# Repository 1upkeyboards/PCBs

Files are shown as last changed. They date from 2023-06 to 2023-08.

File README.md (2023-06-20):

# PCBs
Repository containing production files and schematics for 1upkeyboards pcbs

Shield: [][cc-by-nc-sa]

This work is licensed under a
[Creative Commons Attribution-NonCommercial-ShareAlike 4.0 International License][cc-by-nc-sa].

[][cc-by-nc-sa]

[cc-by-nc-sa]: http://creativecommons.org/licenses/by-nc-sa/4.0/
[cc-by-nc-sa-image]: https://licensebuttons.net/l/by-nc-sa/4.0/88x31.png
[cc-by-nc-sa-shield]: https://img.shields.io/badge/License-CC%20BY--NC--SA%204.0-lightgrey.svg

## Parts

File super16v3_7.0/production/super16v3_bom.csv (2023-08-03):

Designator | Footprint | Quantity | Value | LCSC Part #
C1, C10, C11, C14, C15, C2, C3, C6, C8, C9 | cap_0402_production | 10 | 100n | C77014
C12, C13, C7 | cap_0402_production | 3 | 1u | C77009
C4, C5 | cap_0402_production | 2 | 10u | C77000
D1, D10, D13, D14, D17, D18, D19, D2, D21, D22, D24, D25, D27, D28, D3, D30, D31, D32, D33, D36, D37, D4, D40, D41, D44, D45, D46, D47, D48, D5, D6, D9 | WS2812b_1010 | 32 | ws2812b_1010 | C5349953
D11, D12, D15, D16, D20, D23, D26, D29, D7, D8 | SK6812MINI-E RL_production | 10 | SK6812MINI-E | C524051
D34, D35, D38, D39, D42, D43 | SK6812MINI-E LR_production | 6 | SK6812MINI-E | C524051
F1 | fuse_0805_production | 1 | Polyfuse_Small | C2833485
K1, K10, K11, K12, K13, K14, K15, K16, K2, K3, K4, K5, K6, K7, K8, K9 | MXOnly-1U-Hotswap_no_silk_screen | 16 | KEYSW | C5156480 | Kailh: CPG151101S11
R1, R2 | resistor_0402_production | 2 | 27 | C227342
R3 | resistor_0402_production | 1 | 1k | C375497
R4, R5 | resistor_0402_production | 2 | 5.1k | C138073
SW1 | reset_switch_TL3342_production | 1 | SW_Push | C2886894
U1 | voltage_regulator_production | 1 | XC6206PxxxMR | C347376
U2 | emi_production | 1 | ECMF02-4CMX8 | C717678
U3 | rp2040_flash_production | 1 | W25Q128JVS | C2843335
U4 | rp2040_production | 1 | RP2040 | C2040
USB1 | usb_c_production | 1 | HRO-TYPE-C-31-M-12 | C165948
Y1 | resonator_3_pin_production | 1 | Resonator | C341520

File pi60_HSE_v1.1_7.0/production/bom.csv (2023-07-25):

Designator | Footprint | Quantity | Value | LCSC Part #
C1, C12, C2, C3, C4, C5, C6, C7, C8, C9 | 402 | 10 | 100n | C77014
C10, C11, C15 | 402 | 3 | 1u | C77009
C13, C14 | 805 | 2 | 10u | C77075
D1, D10, D11, D12, D13, D14, D15, D16, D17, D18, D19, D2, D20, D21, D22, D23, D24, D25, D26, D27, D28, D29, D3, D30, D31, D32, D33, D34, D35, D36, D37, D38, D39, D4, D40, D41, D42, D43, D44, D45, D46, D47, D48, D49, D5, D50, D51, D52, D53, D54, D55, D56, D57, D58, D59, D6, D60, D61, D62, D63, D7, D8, D9 | D_SOD-123 | 63 | D | C83528
D64, D65, D66, D67, D68, D69, D70, D71, D72, D73, D74, D75, D76, D77, D78, D79 | LED_WS2812B_PLCC4_5.0x5.0mm_P3.2mm | 16 | WS2812B | C2761795
F1 | 1206 | 1 | Polyfuse_Small | C70076
J3 | 1X04_1MM_RA | 1 | QWIIC_CONNECTORJS-1MM | C160404
K1 - K73 | MXOnly-1U-Hotswap | 73 |  | C5156480 | Kailh: CPG151101S11
R1, R2 | 402 | 2 | 27 | C227342
R3 | 402 | 1 | 1k | C375497
R4, R5 | 402 | 2 | 2.2k | C326602
R6, R7 | 402 | 2 | 5.1k | C138073
SW1 | SW_SPST_TL3342 | 1 | SW_Push | C2886894
U1 | RP2040-QFN-56 | 1 | RP2040 | C2040
U2 | PSON50P300X200X60-9N | 1 | W25Q128JVS | C2843335
U3 | ECMF02-4CMX8 | 1 | ECMF02-4CMX8 | C717678
U4 | SOT-23 | 1 | XC6206PxxxMR | C347376
USB1 | HRO-TYPE-C-31-M-12-Assembly | 1 | HRO-TYPE-C-31-M-12 | C165948
Y1 | 3 Pin Resonator | 1 | Resonator | C341520

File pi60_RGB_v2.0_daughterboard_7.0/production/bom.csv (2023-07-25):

Designator | Footprint | Quantity | Value | LCSC Part #
C1, C12, C2, C3, C4, C5, C6, C7, C8, C9 | cap_0402_production | 10 | 100n | C77014
C10, C11, C15 | cap_0402_production | 3 | 1u | C77009
C13, C14 | cap_0402_production | 2 | 10u | C77000
D1, D10, D11, D12, D13, D14, D15, D16, D17, D18, D19, D2, D20, D21, D22, D23, D24, D25, D26, D27, D28, D29, D3, D30, D31, D32, D33, D34, D35, D36, D37, D38, D39, D4, D40, D41, D42, D43, D44, D45, D46, D47, D48, D49, D5, D50, D51, D52, D53, D54, D55, D56, D57, D58, D59, D6, D60, D61, D7, D8, D9 | diode_SOD-123_production | 61 | D | C83528
D100, D101, D102, D64, D65, D66, D67, D68, D69, D70, D71, D72, D73, D74, D75, D90, D91, D92, D93, D94, D95, D96, D97, D98, D99 | SK6812MINI-E RL_production | 25 | SK6812MINI-E | C524051
D103, D104, D105, D106, D107, D108, D109, D110, D111, D112, D113, D114, D116, D118, D120, D121, D122, D148, D149, D151, D153, D155, D62, D63, D76, D77, D78, D79, D80, D81, D82, D83, D84, D85, D86, D87, D88, D89 | SK6812MINI-E LR_production | 38 | SK6812MINI-E | C524051
D115, D117, D119, D123, D125, D126, D127, D128, D129, D130, D131, D132, D133, D134, D135, D136, D137, D138, D139, D140, D141, D142, D143, D144, D145, D146, D147, D150, D152, D154, D156, D157, D158, D159, D160, D161, D162, D163, D164, D165 | WS2812b_1010 | 40 | 1010 | C5349953
J2 | qwiic_stemmaqt_conn_production | 1 | Unified_Daughterboard | C160404
K1-K61 | MXOnly-1U-Hotswap_no_silk_screen | 61 |  | C5156480 | Kailh: CPG151101S11
R1, R2 | resistor_0402_production | 2 | 27 | C227342
R4 | resistor_0402_production | 1 | 1k | C375497
SW1 | reset_switch_TL3342_production | 1 | SW_Push | C2886894
U2 | rp2040_production | 1 | RP2040 | C2040
U3 | rp2040_flash_production | 1 | W25Q128JVS | C2843335
U5 | voltage_regulator_production | 1 | XC6206PxxxMR | C347376
Y1 | resonator_3_pin_production | 1 | Resonator | C341520

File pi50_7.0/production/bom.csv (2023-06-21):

Designator | Footprint | Quantity | Value | LCSC Part #
D1, D10, D11, D12, D13, D14, D15, D16, D17, D18, D19, D2, D20, D21, D22, D23, D24, D25, D26, D27, D28, D29, D3, D30, D31, D32, D33, D34, D35, D36, D37, D38, D39, D4, D40, D41, D42, D43, D44, D45, D46, D47, D48, D49, D5, D50, D51, D52, D53, D54, D55, D56, D57, D58, D59, D6, D60, D7, D8, D9 | Diode No Label | 60 | D
D100, D101, D102, D103, D104, D105, D106, D107, D108, D73, D74, D75, D76, D77, D78, D79, D80, D81, D82, D83, D84, D97, D98, D99 | MX_SK6812MINI-E LR no keepout no via | 24 | SK6812MINI-E
D109, D110, D111, D112, D113, D114, D115, D116, D117, D118, D119, D120, D121, D61, D62, D63, D64, D65, D66, D67, D68, D69, D70, D71, D72, D85, D86, D87, D88, D89, D90, D91, D92, D93, D94, D95, D96 | MX_SK6812MINI-E RL no keepout no via | 37 | SK6812MINI-E
H1, H2, H3, H4 | MountingHole_3.2mm_M3 | 4 | MountingHole
H10, H5, H6, H7, H8, H9 | MountingHole_5.3mm_M5 | 6 | MountingHole
J1 | PinHeader_1x15_P2.54mm_Vertical | 1 | Conn_01x15_Female
J2 | PinHeader_1x04_P2.54mm_Vertical | 1 | I2C Display
K1, K10, K11, K12, K13, K14, K15, K16, K17, K18, K19, K2, K20, K21, K22, K23, K24, K25, K26, K27, K28, K29, K3, K30, K31, K32, K33, K34, K35, K36, K37, K38, K39, K4, K40, K41, K42, K43, K44, K45, K46, K47, K48, K49, K5, K50, K51, K52, K53, K54, K55, K56, K57, K58, K59, K6, K60, K7, K8, K9 | MXOnly-1U-NoLED_tight | 60 | KEYSW
K61 | MXOnly-2U-ReversedStabilizers-NoLED_tight | 1 | KEYSW
SW1 | RotaryEncoder_EC11 | 1 | Rotary_Encoder_Switch
U1 | MODULE_SC0915 | 1 | SC0915

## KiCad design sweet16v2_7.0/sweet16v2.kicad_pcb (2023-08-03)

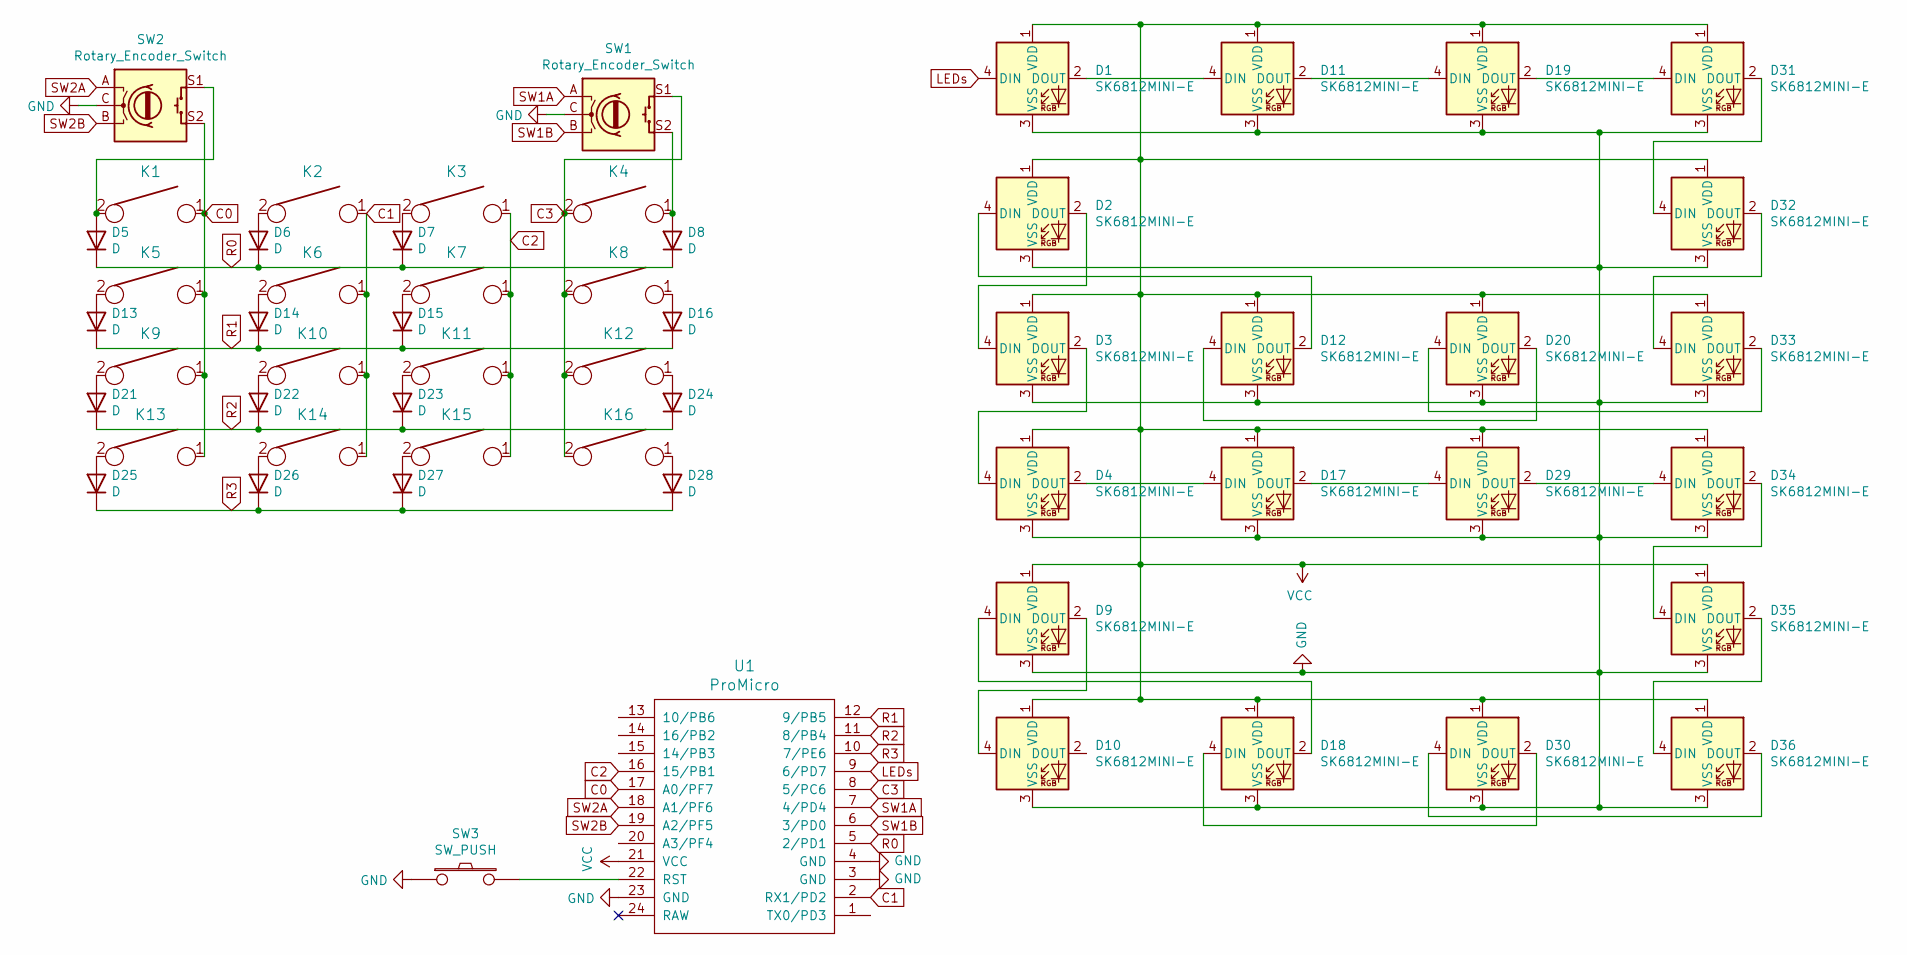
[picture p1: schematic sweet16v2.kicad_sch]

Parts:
D1, D3, D4, D10, D11, D12, D17, D18, D19, D20, D29, D30, D31, D33, D34, D36: SK6812MINI-E; MX_SK6812MINI-E_upward_facing
D2, D9, D32, D35: SK6812MINI-E; MX_SK6812MINI-E_flipped
D5, D6, D7, D8, D13, D14, D15, D16, D21, D22, D23, D24, D25, D26, D27, D28: D; D_SOD123_axial
K1, K2, K3, K4, K5, K6, K7, K8, K9, K10, K11, K12, K13, K14, K15, K16: KEYSW; MXOnly-1U-NoLED
SW1, SW2: Rotary_Encoder_Switch; RotaryEncoder_EC11
SW3: SW_PUSH; SW_SPST_TL3342
U1: ProMicro; ArduinoProMicro

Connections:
C0: K1.1, K5.1, K9.1, K13.1, SW2.S2, U1.17 (A0/PF7)
C1: K2.1, K6.1, K10.1, K14.1, U1.2 (RX1/PD2)
C2: K3.1, K7.1, K11.1, K15.1, U1.16 (15/PB1)
C3: K4.2, K8.2, K12.2, K16.2, SW1.S1, U1.8 (5/PC6)
GND: D1.3 (VSS), D2.3 (VSS), D3.3 (VSS), D4.3 (VSS), D9.3 (VSS), D10.3 (VSS), D11.3 (VSS), D12.3 (VSS), D17.3 (VSS), D18.3 (VSS), D19.3 (VSS), D20.3 (VSS), D29.3 (VSS), D30.3 (VSS), D31.3 (VSS), D32.3 (VSS), D33.3 (VSS), D34.3 (VSS), D35.3 (VSS), D36.3 (VSS), SW1.C, SW2.C, SW3.1, U1.3 (GND), U1.4 (GND), U1.23 (GND)
LEDs: D1.4 (DIN), U1.9 (6/PD7)
unnamed: D1.2 (DOUT), D11.4 (DIN)
unnamed: D2.2 (DOUT), D3.4 (DIN)
unnamed: D3.2 (DOUT), D4.4 (DIN)
unnamed: D5.2 (A), K1.2, SW2.S1
unnamed: D6.2 (A), K2.2
unnamed: D7.2 (A), K3.2
unnamed: D8.2 (A), K4.1, SW1.S2
unnamed: D9.2 (DOUT), D10.4 (DIN)
unnamed: D11.2 (DOUT), D19.4 (DIN)
unnamed: D2.4 (DIN), D12.2 (DOUT)
unnamed: D12.4 (DIN), D20.2 (DOUT)
unnamed: D13.2 (A), K5.2
unnamed: D14.2 (A), K6.2
unnamed: D15.2 (A), K7.2
unnamed: D16.2 (A), K8.1
unnamed: D17.2 (DOUT), D29.4 (DIN)
unnamed: D4.2 (DOUT), D17.4 (DIN)
unnamed: D9.4 (DIN), D18.2 (DOUT)
unnamed: D18.4 (DIN), D30.2 (DOUT)
unnamed: D19.2 (DOUT), D31.4 (DIN)
unnamed: D20.4 (DIN), D33.2 (DOUT)
unnamed: D21.2 (A), K9.2
unnamed: D22.2 (A), K10.2
unnamed: D23.2 (A), K11.2
unnamed: D24.2 (A), K12.1
unnamed: D25.2 (A), K13.2
unnamed: D26.2 (A), K14.2
unnamed: D27.2 (A), K15.2
unnamed: D28.2 (A), K16.1
unnamed: D29.2 (DOUT), D34.4 (DIN)
unnamed: D30.4 (DIN), D36.2 (DOUT)
unnamed: D31.2 (DOUT), D32.4 (DIN)
unnamed: D32.2 (DOUT), D33.4 (DIN)
unnamed: D34.2 (DOUT), D35.4 (DIN)
unnamed: D35.2 (DOUT), D36.4 (DIN)
unnamed: SW3.2, U1.22 (RST)
R0: D5.1 (K), D6.1 (K), D7.1 (K), D8.1 (K), U1.5 (2/PD1)
R1: D13.1 (K), D14.1 (K), D15.1 (K), D16.1 (K), U1.12 (9/PB5)
R2: D21.1 (K), D22.1 (K), D23.1 (K), D24.1 (K), U1.11 (8/PB4)
R3: D25.1 (K), D26.1 (K), D27.1 (K), D28.1 (K), U1.10 (7/PE6)
SW1A: SW1.A, U1.7 (4/PD4)
SW1B: SW1.B, U1.6 (3/PD0)
SW2A: SW2.A, U1.18 (A1/PF6)
SW2B: SW2.B, U1.19 (A2/PF5)
VCC: D1.1 (VDD), D2.1 (VDD), D3.1 (VDD), D4.1 (VDD), D9.1 (VDD), D10.1 (VDD), D11.1 (VDD), D12.1 (VDD), D17.1 (VDD), D18.1 (VDD), D19.1 (VDD), D20.1 (VDD), D29.1 (VDD), D30.1 (VDD), D31.1 (VDD), D32.1 (VDD), D33.1 (VDD), D34.1 (VDD), D35.1 (VDD), D36.1 (VDD), U1.21 (VCC)

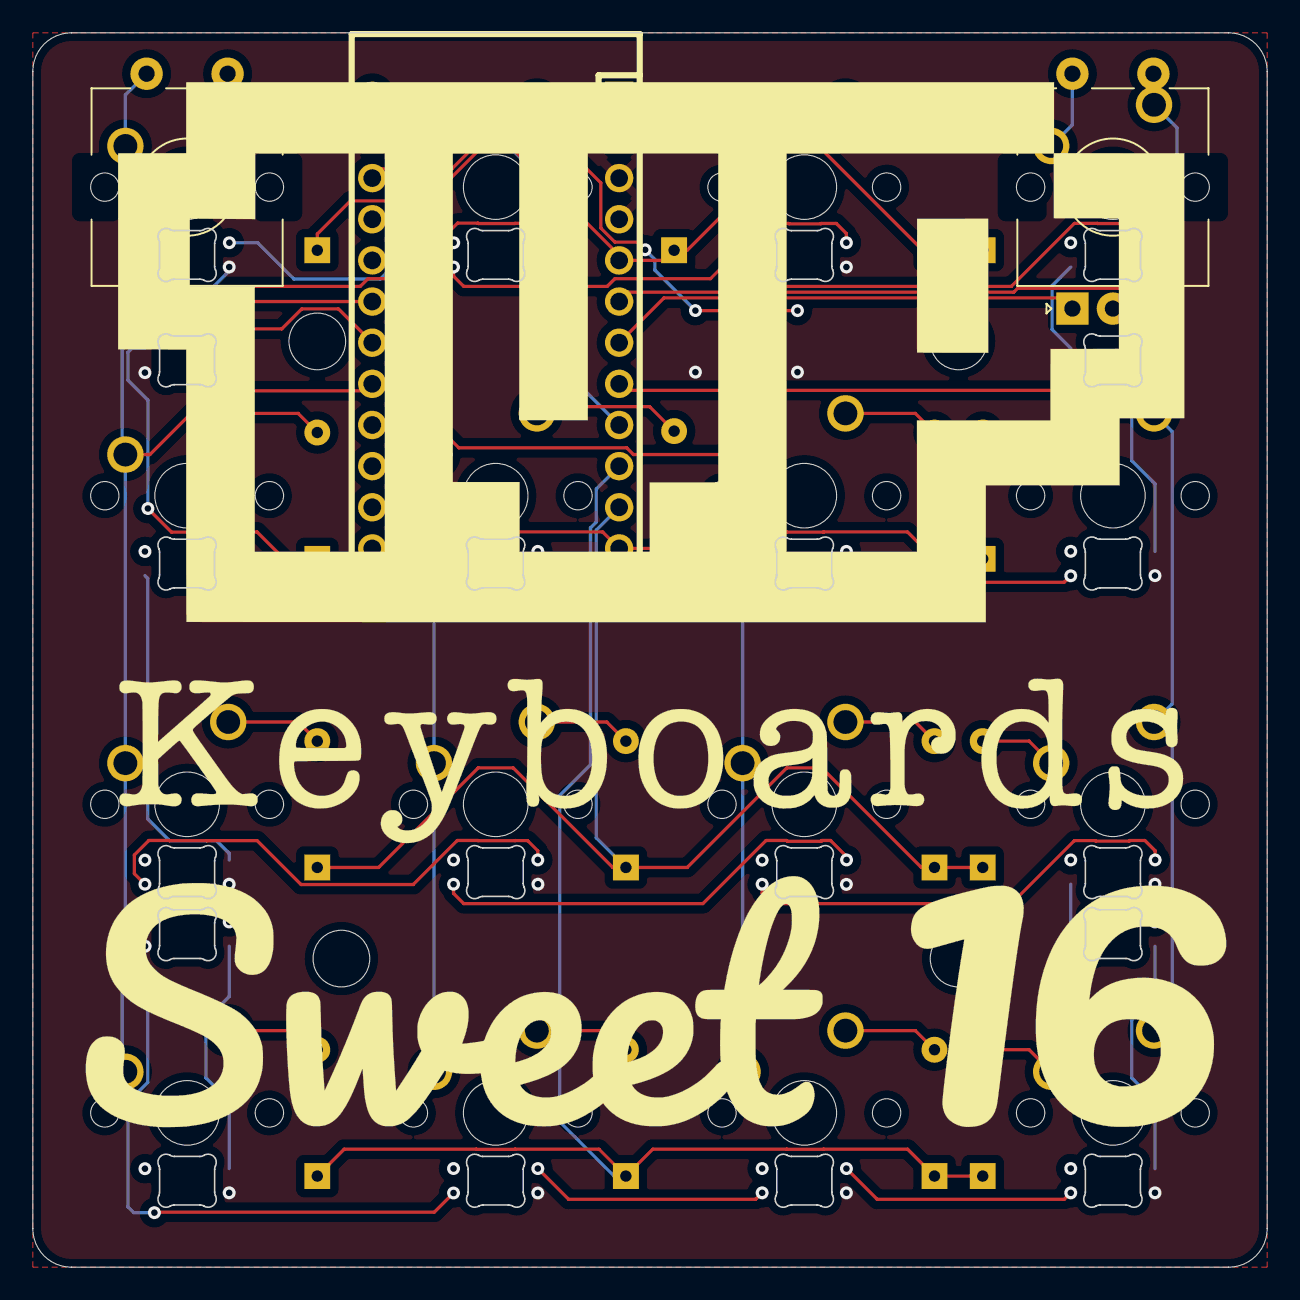
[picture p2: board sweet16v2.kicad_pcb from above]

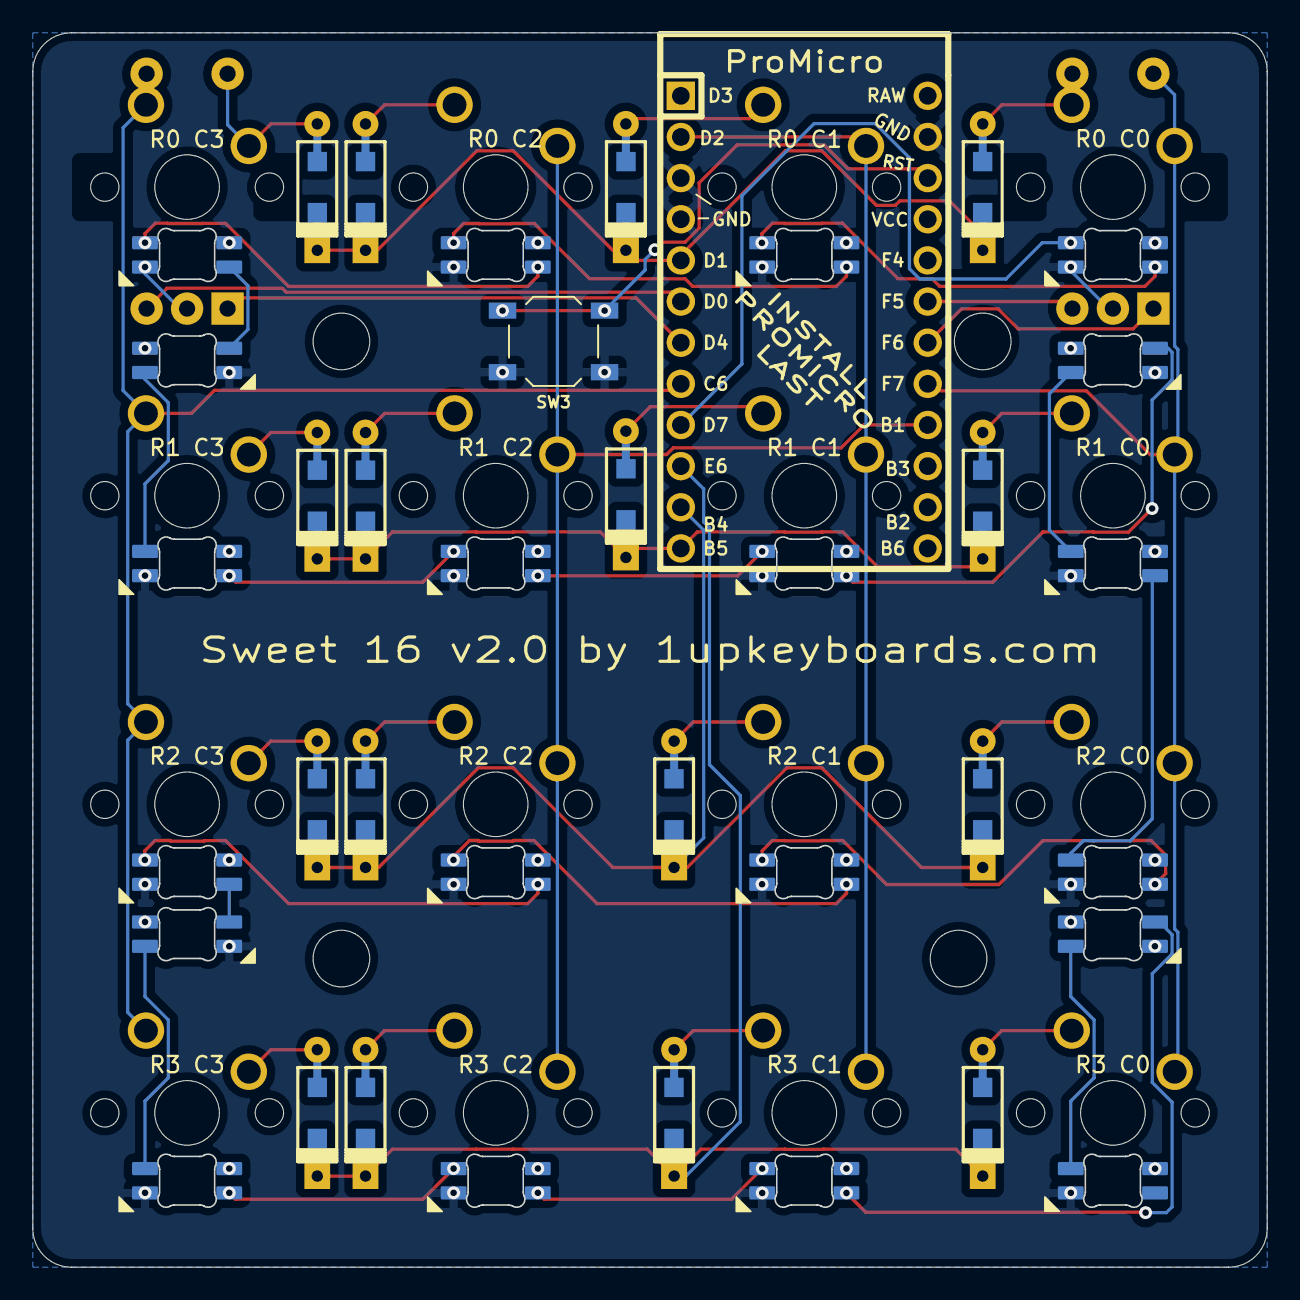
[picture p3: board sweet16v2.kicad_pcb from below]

Board: 4 copper layers, 76.2 x 76.2 mm, 56 parts (18 on the bottom side), 51 nets.

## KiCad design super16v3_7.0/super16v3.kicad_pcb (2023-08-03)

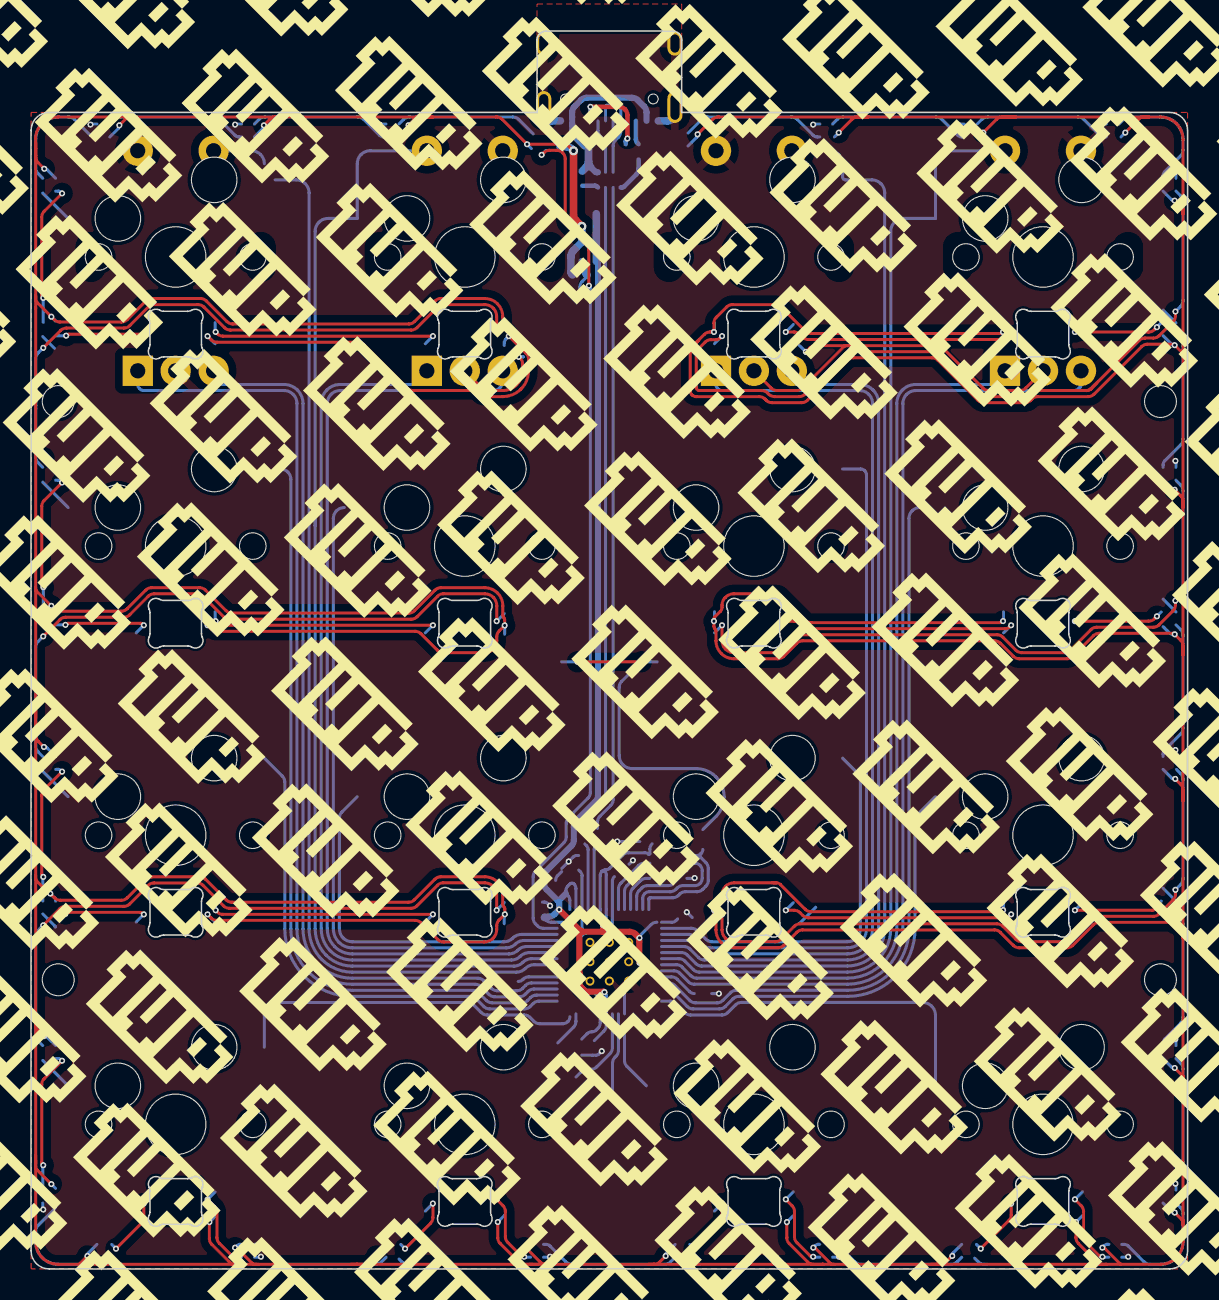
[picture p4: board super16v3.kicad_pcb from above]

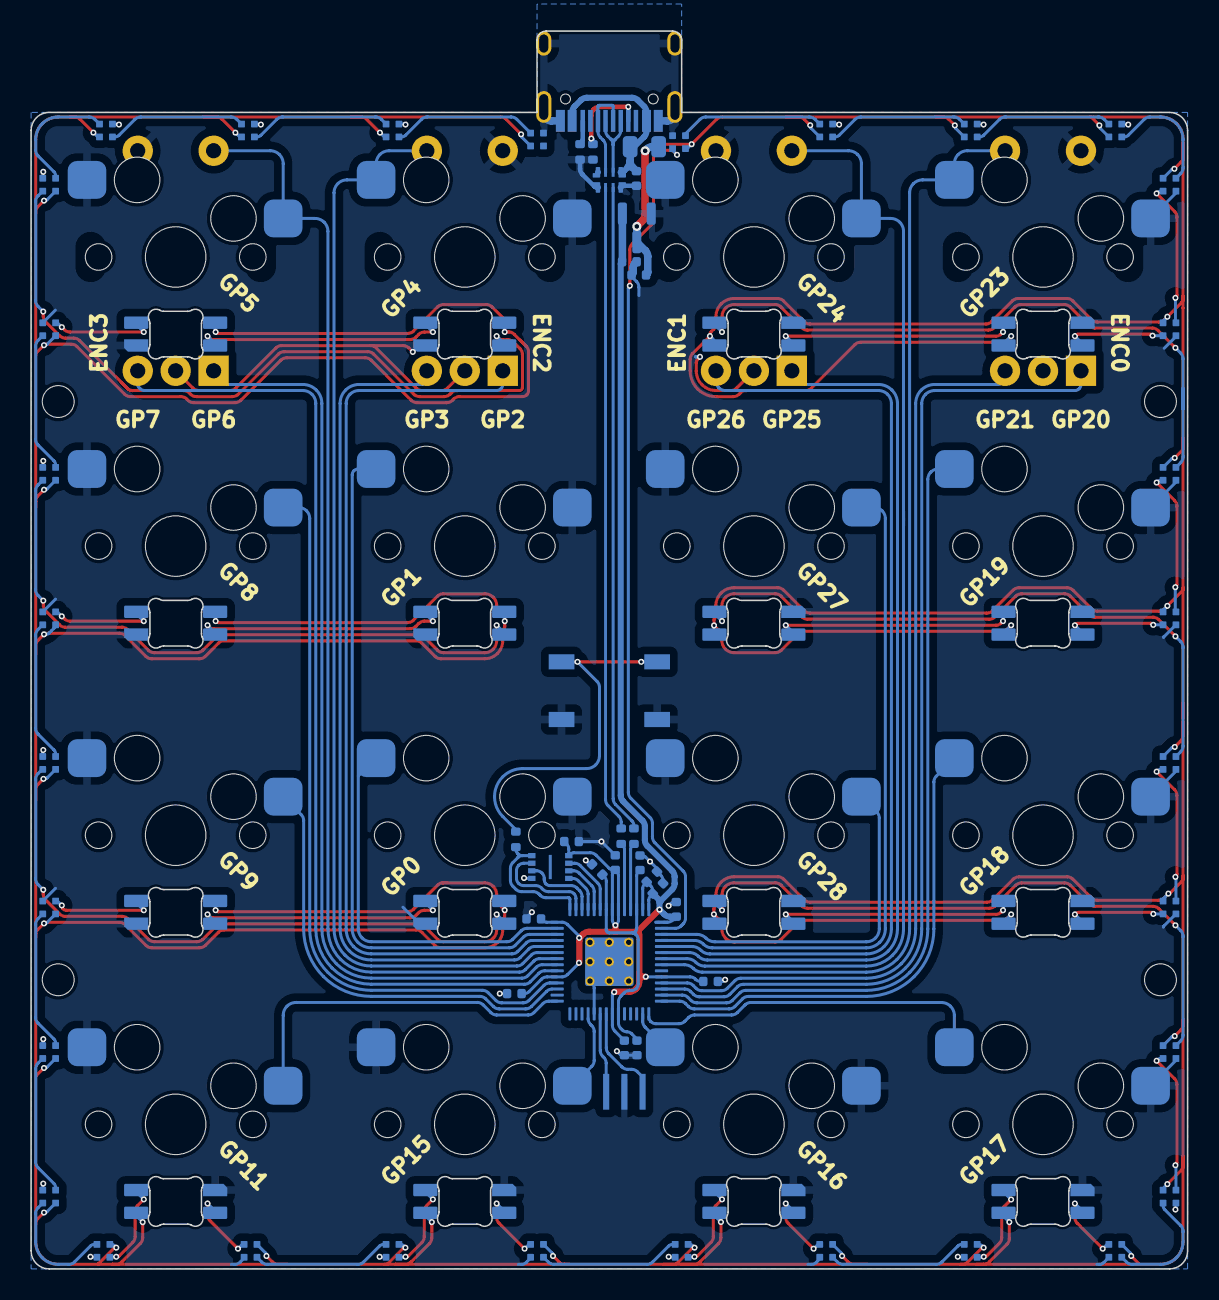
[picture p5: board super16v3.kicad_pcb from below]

Board: 2 copper layers, 76.2 x 81.6 mm, 100 parts (28 on the bottom side), 94 nets.

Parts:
C1, C2, C3, C6, C8, C9, C10, C11, C14, C15: 100n; cap_0402_production
C4, C5: 10u; cap_0402_production
C7, C12, C13: 1u; cap_0402_production
D1, D2, D3, D4, D5, D6, D9, D10, D13, D14, D17, D18, D19, D21, D22, D24, D25, D27, D28, D30, D31, D32, D33, D36, D37, D40, D41, D44, D45, D46, D47, D48: ws2812b_1010; WS2812b_1010
D7, D8, D11, D12, D15, D16, D20, D23, D26, D29: SK6812MINI-E; SK6812MINI-E RL_production
D34, D35, D38, D39, D42, D43: SK6812MINI-E; SK6812MINI-E LR_production
F1: Polyfuse_Small; fuse_0805_production
H1, H2, H3, H4: MountingHole; m2_mount
K1, K2, K3, K4, K5, K6, K7, K8, K9, K10, K11, K12, K13, K14, K15, K16: KEYSW; MXOnly-1U-Hotswap_no_silk_screen
R1, R2: 27; resistor_0402_production
R3: 1k; resistor_0402_production
R4, R5: 5.1k; resistor_0402_production
SW1: SW_Push; reset_switch_TL3342_production
SW2, SW3, SW4, SW5: Rotary_Encoder_Switch; encoder_production
U1: XC6206PxxxMR; voltage_regulator_production
U2: ECMF02-4CMX8; emi_production
U3: W25Q128JVS; rp2040_flash_production
U4: RP2040; rp2040_production
USB1: HRO-TYPE-C-31-M-12; usb_c_production
Y1: Resonator; resonator_3_pin_production

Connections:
+1V1: C13.2, C14.2, C15.2, U4.23 (DVDD), U4.45 (VREG_VOUT), U4.50 (DVDD)
+3V3: C1.2, C2.2, C3.2, C5.1, C6.1, C8.2, C9.2, C10.2, C11.2, C12.2, U1.2 (VO), U3.8 (VCC), U4.1 (IOVDD), U4.10 (IOVDD), U4.22 (IOVDD), U4.33 (IOVDD), U4.42 (IOVDD), U4.43 (ADC_AVDD), U4.44 (VREG_IN), U4.48 (USB_VDD), U4.49 (IOVDD)
+5V: C4.1, D1.1 (VDD), D2.1 (VDD), D3.1 (VDD), D4.1 (VDD), D5.1 (VDD), D6.1 (VDD), D7.1 (VDD), D8.1 (VDD), D9.1 (VDD), D10.1 (VDD), D11.1 (VDD), D12.1 (VDD), D13.1 (VDD), D14.1 (VDD), D15.1 (VDD), D16.1 (VDD), D17.1 (VDD), D18.1 (VDD), D19.1 (VDD), D20.1 (VDD), D21.1 (VDD), D22.1 (VDD), D23.1 (VDD), D24.1 (VDD), D25.1 (VDD), D26.1 (VDD), D27.1 (VDD), D28.1 (VDD), D29.1 (VDD), D30.1 (VDD), D31.1 (VDD), D32.1 (VDD), D33.1 (VDD), D34.1 (VDD), D35.1 (VDD), D36.1 (VDD), D37.1 (VDD), D38.1 (VDD), D39.1 (VDD), D40.1 (VDD), D41.1 (VDD), D42.1 (VDD), D43.1 (VDD), D44.1 (VDD), D45.1 (VDD), D46.1 (VDD), D47.1 (VDD), D48.1 (VDD), F1.2, U1.3 (VI)
/QSPI_SCLK: U3.6 (CLK), U4.52 (QSPI_SCLK)
/QSPI_SD0: U3.5 (DI(IO0)), U4.53 (QSPI_SD0)
/QSPI_SD1: U3.2 (DO(IO1)), U4.55 (QSPI_SD1)
/QSPI_SD2: U3.3 (IO2), U4.54 (QSPI_SD2)
/QSPI_SD3: U3.7 (IO3), U4.51 (QSPI_SD3)
/QSPI_SS: R3.1, U3.1 (~CS), U4.56 (QSPI_SS)
DN_USB: U2.2 (D-), USB1.5 (DN2), USB1.7 (DN1)
DP_USB: U2.3 (D+), USB1.6 (DP1), USB1.8 (DP2)
unnamed: D1.2 (DOUT), D2.4 (DIN)
unnamed: D2.2 (DOUT), D3.4 (DIN)
unnamed: D3.2 (DOUT), D4.4 (DIN)
unnamed: D4.2 (DOUT), D5.4 (DIN)
unnamed: D5.2 (DOUT), D6.4 (DIN)
unnamed: D6.2 (DOUT), D7.4 (DIN)
unnamed: D7.2 (DOUT), D8.4 (DIN)
unnamed: D8.2 (DOUT), D9.4 (DIN)
unnamed: D9.2 (DOUT), D10.4 (DIN)
unnamed: D10.2 (DOUT), D11.4 (DIN)
unnamed: D11.2 (DOUT), D12.4 (DIN)
unnamed: D12.2 (DOUT), D13.4 (DIN)
unnamed: D13.2 (DOUT), D14.4 (DIN)
unnamed: D14.2 (DOUT), D15.4 (DIN)
unnamed: D15.2 (DOUT), D16.4 (DIN)
unnamed: D16.2 (DOUT), D17.4 (DIN)
unnamed: D17.2 (DOUT), D18.4 (DIN)
unnamed: D18.2 (DOUT), D19.4 (DIN)
unnamed: D19.2 (DOUT), D20.4 (DIN)
unnamed: D20.2 (DOUT), D21.4 (DIN)
unnamed: D21.2 (DOUT), D22.4 (DIN)
unnamed: D22.2 (DOUT), D23.4 (DIN)
unnamed: D23.2 (DOUT), D24.4 (DIN)
unnamed: D24.2 (DOUT), D25.4 (DIN)
unnamed: D25.2 (DOUT), D26.4 (DIN)
unnamed: D26.2 (DOUT), D27.4 (DIN)
unnamed: D27.2 (DOUT), D28.4 (DIN)
unnamed: D28.2 (DOUT), D29.4 (DIN)
unnamed: D29.2 (DOUT), D30.4 (DIN)
unnamed: D30.2 (DOUT), D31.4 (DIN)
unnamed: D31.2 (DOUT), D32.4 (DIN)
unnamed: D32.2 (DOUT), D33.4 (DIN)
unnamed: D33.2 (DOUT), D34.4 (DIN)
unnamed: D34.2 (DOUT), D35.4 (DIN)
unnamed: D35.2 (DOUT), D36.4 (DIN)
unnamed: D36.2 (DOUT), D37.4 (DIN)
unnamed: D37.2 (DOUT), D38.4 (DIN)
unnamed: D38.2 (DOUT), D39.4 (DIN)
unnamed: D39.2 (DOUT), D40.4 (DIN)
unnamed: D40.2 (DOUT), D41.4 (DIN)
unnamed: D41.2 (DOUT), D42.4 (DIN)
unnamed: D42.2 (DOUT), D43.4 (DIN)
unnamed: D43.2 (DOUT), D44.4 (DIN)
unnamed: D44.2 (DOUT), D45.4 (DIN)
unnamed: D45.2 (DOUT), D46.4 (DIN)
unnamed: D46.2 (DOUT), D47.4 (DIN)
unnamed: D47.2 (DOUT), D48.4 (DIN)
unnamed: R1.1, U2.6 (D+)
unnamed: R2.1, U2.7 (D-)
unnamed: R3.2, SW1.1
unnamed: R2.2, U4.46 (USB_DM)
unnamed: R1.2, U4.47 (USB_DP)
unnamed: U4.20 (XIN), Y1.3
unnamed: U4.21 (XOUT), Y1.1
unnamed: R4.2, USB1.4 (CC1)
unnamed: R5.2, USB1.10 (CC2)
VCC: C7.1, F1.1, U2.1 (VBUS), USB1.2 (VBUS), USB1.11 (VBUS)
gnd: C1.1, C2.1, C3.1, C4.2, C5.2, C6.2, C7.2, C8.1, C9.1, C10.1, C11.1, C12.1, C13.1, C14.1, C15.1, D1.3 (VSS), D2.3 (VSS), D3.3 (VSS), D4.3 (VSS), D5.3 (VSS), D6.3 (VSS), D7.3 (VSS), D8.3 (VSS), D9.3 (VSS), D10.3 (VSS), D11.3 (VSS), D12.3 (VSS), D13.3 (VSS), D14.3 (VSS), D15.3 (VSS), D16.3 (VSS), D17.3 (VSS), D18.3 (VSS), D19.3 (VSS), D20.3 (VSS), D21.3 (VSS), D22.3 (VSS), D23.3 (VSS), D24.3 (VSS), D25.3 (VSS), D26.3 (VSS), D27.3 (VSS), D28.3 (VSS), D29.3 (VSS), D30.3 (VSS), D31.3 (VSS), D32.3 (VSS), D33.3 (VSS), D34.3 (VSS), D35.3 (VSS), D36.3 (VSS), D37.3 (VSS), D38.3 (VSS), D39.3 (VSS), D40.3 (VSS), D41.3 (VSS), D42.3 (VSS), D43.3 (VSS), D44.3 (VSS), D45.3 (VSS), D46.3 (VSS), D47.3 (VSS), D48.3 (VSS), K1.1, K2.2, K3.1, K4.2, K5.1, K6.2, K7.1, K8.2, K9.1, K10.2, K11.1, K12.2, K13.1, K14.1, K15.2, K16.2, R4.1, R5.1, SW1.2, SW2.C, SW2.S2, SW3.C, SW3.S1, SW4.C, SW4.S2, SW5.C, SW5.S1, U1.1 (GND), U2.5 (GND), U2.8 (GND), U3.4 (GND), U4.19 (TESTEN), U4.57 (GND), USB1.1 (GND), USB1.12 (GND), USB1.13 (SHIELD), Y1.2
gp0: K11.2, U4.2 (GPIO0)
gp1: K7.2, U4.3 (GPIO1)
gp4: K3.2, SW4.S1, U4.6 (GPIO4)
gp5: K4.1, SW5.S2, U4.7 (GPIO5)
gp8: K8.1, U4.11 (GPIO8)
gp9: K12.1, U4.12 (GPIO9)
gp11: K16.1, U4.14 (GPIO11)
gp15: K15.1, U4.18 (GPIO15)
gp16: K14.2, U4.27 (GPIO16)
gp17: K13.2, U4.28 (GPIO17)
gp18: K9.2, U4.29 (GPIO18)
gp19: K5.2, U4.30 (GPIO19)
gp23: K1.2, SW2.S1, U4.35 (GPIO23)
gp24: K2.1, SW3.S2, U4.36 (GPIO24)
gp27: K6.1, U4.39 (GPIO27_ADC1)
gp28: K10.1, U4.40 (GPIO28_ADC2)
rgb: D1.4 (DIN), U4.41 (GPIO29_ADC3)
sw2_a: SW2.A, U4.31 (GPIO20)
sw2_b: SW2.B, U4.32 (GPIO21)
sw3_a: SW3.A, U4.37 (GPIO25)
sw3_b: SW3.B, U4.38 (GPIO26_ADC0)
sw4_a: SW4.A, U4.4 (GPIO2)
sw4_b: SW4.B, U4.5 (GPIO3)
sw5_a: SW5.A, U4.8 (GPIO6)
sw5_b: SW5.B, U4.9 (GPIO7)

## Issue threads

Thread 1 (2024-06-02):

The file for pi60_rgb_v2 is wrong

F1hone, 2024-06-02:
The wiring of the last row of RGB lights is reversed
the lights will not light up.
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

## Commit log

2023-06-21 add pi50
    [bom.csv, pi50.kicad_sch, pi50.sch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]
2023-07-25 Updates to PCBs
    [bom.csv, pi60_HSE_v1.1.kicad_sch, pi60_RGB_v2.0_usb.kicad_sch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]
2023-08-03 addition of super16v3
    [super16v3.kicad_pcb, super16v3.kicad_sch, super16v3_bom.csv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]
2023-08-03 add pi40
    [pi40_v1.1.kicad_sch]
2023-08-03 add sweet16v2
    [sweet16v2.kicad_pcb, sweet16v2.kicad_sch]

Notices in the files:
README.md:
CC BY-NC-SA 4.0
